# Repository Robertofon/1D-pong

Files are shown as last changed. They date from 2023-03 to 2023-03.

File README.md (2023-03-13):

# 1D-pong

This is an ESP32 (at least that) version of the all well known warareg 1-D Pong game
also known as `one_d_pong`.

This is a linear pong game where the bat is a home area of about 7 pixels. Depending on
how deep you let the ball run into your home area, the faster it is repelled. If you 
fail to press the button in time you loose a point since the ball enters your home.
This version supports a boost button which sacrefies one pixel of your home area in 
favor of boosting your ball faster.

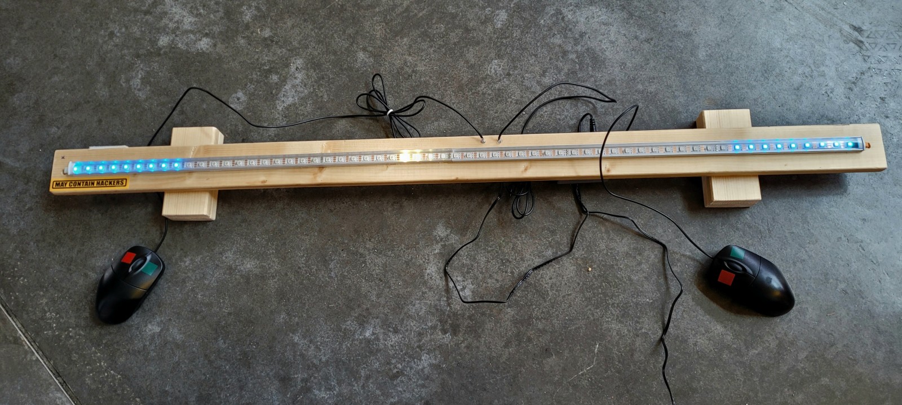
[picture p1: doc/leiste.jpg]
Full 1D-pong device


We discovered that using these Pins for I/O was a good choice

* GPIO21 = LED data (WS2812b)
* GPIO19 = Right start/hit button (Y)
* GPIO18 = Right power-up button  (Y)
* GPIO33 = Left start/hit button  (X)
* GPIO23 = Left power-up button   (X)
* SOUND GPIO32  = Buzzer output (PB1/OC1A)

Some pins do not allow to configure Pull up resistors or work only as output. Don't use them.

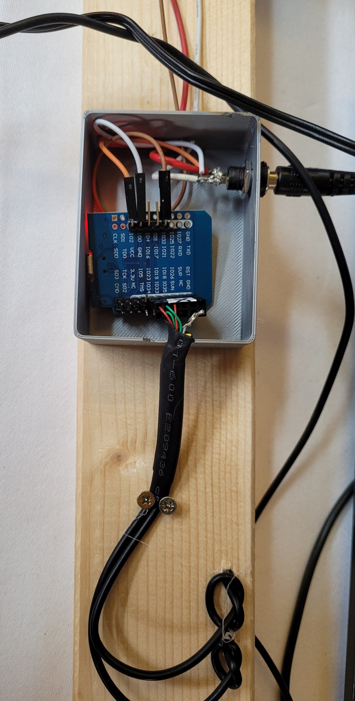
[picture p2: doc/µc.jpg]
The ESP32 of that shape with Pins connected


We used Mouse devices which where re-soldered to use the 4 USB wires as 'short to GND' to work as controllers. 
That is, each button got explicitly one of the Din, Dout, Vcc wires and shorts it to the GND wire of USB.
USB plugs where of course snipped off.
We also did re-solder some of the existing capacitors of the USB-logic board and put them in parallel to the
switch to suppress electric bouncing of the switch signal.

One way of wiring everything up (you can vary for geometry reasons) can be seen here.
We respected the types of PINs and their capability. i.e. all switch pins must support
pull up resistors (configurable property of ESP32) and work as digital input. 
The buzzer sound pin must be supported by the PWM generator. (Not yet used by the code)

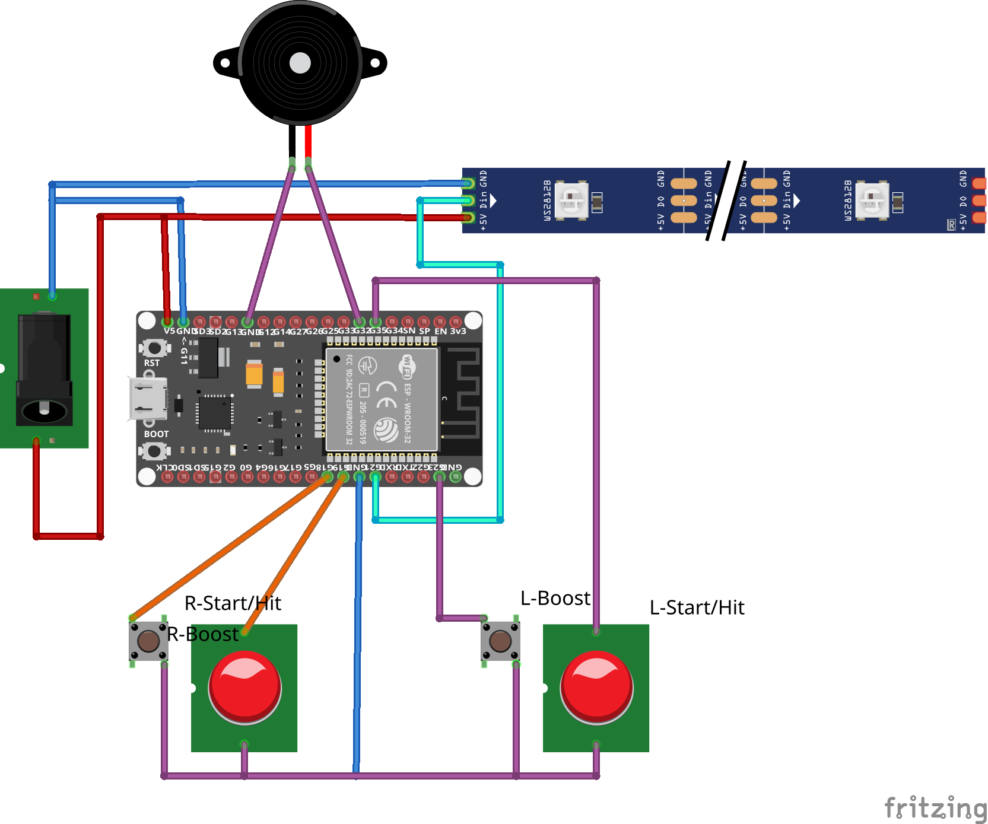
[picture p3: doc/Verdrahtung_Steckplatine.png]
Layout


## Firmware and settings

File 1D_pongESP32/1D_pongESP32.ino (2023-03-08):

/*
 * Arduino 1D Pong Game with (60) WS2812B LEDs
 *
 * Copyright (C) 2015  B.Stultiens
 *
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
 * Adapted by Robert Köpferl 2022 to be used on ESP32 -
 * no optimisation towards atmel
 *
 */

#include <Adafruit_NeoPixel.h>
#include "notes.h"
#include "pin-names.h"

#define NELEM(x) (sizeof(x) / sizeof((x)[0]))

#define PIN_WSDATA GPIO21 // LED data
#define PIN_BUT_RS GPIO19 // Right start/hit button (Y)
#define PIN_BUT_RP GPIO18 // Right power-up button  (Y)
#define PIN_BUT_LS GPIO33 // Left start/hit button  (X)
#define PIN_BUT_LP GPIO23 // Left power-up button   (X)
#define PIN_SOUND GPIO32  // Buzzer output (PB1/OC1A)

#define NPIXELS 60 // Number of pixels to handle

#define ZONE_SIZE 10		// Bounce-back zone size
#define SHOW_LO 12		// Score dots intensity background
#define SHOW_HI 48		// Score dots intensity foreground
#define WIN_POINTS 10	// Points needed to win
#define TONE_INTERVAL 5 // Not every ball move should give a sound

Adafruit_NeoPixel one_d = Adafruit_NeoPixel(NPIXELS, PIN_WSDATA, NEO_GRB | NEO_KHZ800);

// Events from buttons and timers
#define EV_BUT_LS_PRESS 0x01
#define EV_BUT_RS_PRESS 0x02
#define EV_BUT_LP_PRESS 0x04
#define EV_BUT_RP_PRESS 0x08
#define EV_TIMER 0x10
#define EV_TIMEOUT 0x20
#define EV_TONETIMER 0x40

#define TIME_DEBOUNCE 8
#define TIME_IDLE 40
#define TIME_START_TIMEOUT 20000 // Go idle if nothing happens
#define TIME_RESUME_TIMEOUT 7500 // Auto-fire after timeout
#define TIME_BALL_BLINK 150
#define TIME_SPEED_MIN 10
#define TIME_SPEED_INTERVAL 3
#define TIME_POINT_BLINK 233
#define TIME_WIN_BLINK 85
#define TIME_LOCKOUT 250 // Prevent fast button-press to max. 4 times/s

#define TIME_TONE_SERVE 50 // Sound durations
#define TIME_TONE_BOUNCE 50
#define TIME_TONE_MOVE 25
#define TIME_TONE_SCORE 50

enum
{
	ST_IDLE = 0,
	ST_START_L,
	ST_START_R,
	ST_MOVE_LR,
	ST_MOVE_RL,
	ST_ZONE_L,
	ST_ZONE_R,
	ST_POINT_L,
	ST_POINT_R,
	ST_RESUME_L,
	ST_RESUME_R,
	ST_WIN_L,
	ST_WIN_R,
};

static uint32_t oldtime; // Previous' loop millis() value
static uint8_t thestate; // Game state

static uint8_t bstate_ls; // Button states
static uint8_t bstate_rs;
static uint8_t bstate_lp;
static uint8_t bstate_rp;
static uint8_t debtmr_ls; // Button debounce timers
static uint8_t debtmr_rs;
static uint8_t debtmr_lp;
static uint8_t debtmr_rp;
static uint16_t timer;	   // General timer
static uint16_t timeout;   // Timeout timer (auto-start and goto idle)
static uint16_t tonetimer; // Tone duration timer
static uint16_t lockout_l; // Lockout timer to prevent pushing too often
static uint16_t lockout_r;
static uint8_t ballblinkstate;	// Blinking ball at edge on/off
static uint8_t pointblinkcount; // Blinking point when a side scores
static uint8_t ballpos;			// Current position of the ball
static uint16_t speed;			// Time between ball moves
static uint8_t speedup;			// Faster and faster replies counter
static uint8_t points_l;		// Score
static uint8_t points_r;
static uint8_t zone_l; // Hit back zone
static uint8_t zone_r;
static uint8_t boost_l; // Set if user boosted speed last round
static uint8_t boost_r;
static uint8_t boosted;	  // Set if any user boosted until the ball reaches opposite side
static uint8_t tonecount; // Interval counter for sound during move
static uint8_t tuneidx;	  // Index to the running tune

struct tnote
{
	uint8_t note;
	uint16_t duration;
};

/* Tone pitch table for 16MHz crystal */
static const uint16_t tone_pitch[NTONE_PITCH] PROGMEM = {
	61155,
	57722,
	54482,
	51424,
	48538,
	45814,
	43242,
	40815,
	38524,
	36362 /* == 220Hz */,
	34321,
	32395,
	30577,
	28860,
	27240,
	25711,
	24268,
	22906,
	21620,
	20407,
	19261,
	18180 /* == 440Hz */,
	17160,
	16197,
	15288,
	14429,
	13619,
	12855,
	12133,
	11452,
	10809,
	10203,
	9630,
	9089 /* == 880Hz */,
	8579,
	8098,
	7643,
	7214,
	6809,
	6427,
	6066,
	5725,
	5404,
	5101,
	4814,
	4544,
	4289,
	4048,
	3821,
	3606,
	3404,
	3213,
	3032,
	2862,
	2701,
	2550,
	2406,
	2271,
	2144,
	2023,
	1910,
};
static const tnote tune_win[] PROGMEM = {
	{NOTE_Gs6, DUR_1_16},
	{NOTE_A6, DUR_1_16},
	{NOTE_Gs6, DUR_1_16},
	{NOTE_E6, DUR_1_16},
	{NOTE_Gs6, DUR_1_16},
	{NOTE_A6, DUR_1_16},
	{NOTE_Gs6, DUR_1_16},
	{NOTE_E6, DUR_1_16},
	{0, DUR_1_8},
	{NOTE_D4, DUR_1_8},
	{NOTE_D4, DUR_1_8},
	{NOTE_B3, DUR_1_8},
	{NOTE_E4, DUR_1_8},
	{NOTE_D4, DUR_1_4},
	{NOTE_B3, DUR_1_4},
	{NOTE_D4, DUR_1_8},
	{NOTE_D4, DUR_1_8},
	{NOTE_B3, DUR_1_8},
	{NOTE_E4, DUR_1_8},
	{NOTE_D4, DUR_1_4},
	{NOTE_B3, DUR_1_4},
};

// #define sound_off()	do { TCCR1A = _BV(COM1A1); /* Set clear output */ } while(0)
void sound_off()
{
	// stop play
	//noTone(PIN_SOUND);
  ledcDetachPin(PIN_SOUND);
}

/*
 * Return the current state of a button.
 * Returns non-zero on button pressed.
 */
static inline uint8_t button_is_down(uint8_t pin)
{
	switch (pin)
	{
	case PIN_BUT_LS:
		return !debtmr_ls && !bstate_ls;
	case PIN_BUT_RS:
		return !debtmr_rs && !bstate_rs;
	case PIN_BUT_LP:
		return !debtmr_lp && !bstate_lp;
	case PIN_BUT_RP:
		return !debtmr_rp && !bstate_rp;
	}
	return 0;
}

/*
 * Debounce a button and return an event at the rising edge of the detection.
 * The rising edge ensures that there is no delay from pressing the button and
 * the event propagating. It is a prerequisite that the input line is not
 * glitchy.
 * A release event may be generated if the routine is slightly modified.
 */
static inline uint8_t do_debounce(uint8_t tdiff, uint8_t *bstate, uint8_t *debtmr, uint8_t pin, uint8_t ev)
{
	if (0 == *debtmr)
	{
		uint8_t state = digitalRead(pin);
		if (state != *bstate)
		{
			*debtmr = TIME_DEBOUNCE;
			if (!(*bstate = state))
				return ev; // Event on High-to-Low transition of input
						   // else
						   //  return release_event_value
		}
	}
	else
	{
		if (*debtmr >= tdiff)
			*debtmr -= tdiff;
		else
			*debtmr = 0;
	}
	return 0;
}

/*
 * Timer countdown and return an event on timer reaching zero.
 */
static inline uint8_t do_timer(uint8_t tdiff, uint16_t *tmr, uint8_t ev)
{
	if (0 != *tmr)
	{
		if (*tmr >= tdiff)
			*tmr -= tdiff; // Timer countdown
		else
			*tmr = 0;
		// Set event when done counting
		if (0 == *tmr)
			return ev;
	}
	return 0;
}

/*
 * Set the speaker to generate a tone
 */
static inline void set_tone(uint16_t note, uint16_t duration)
{
	tonetimer = duration;
	if (note && note <= NTONE_PITCH)
	{
		// to calculate the note duration, take one second divided by the note type.
		//e.g. quarter note = 1000 / 4, eighth note = 1000/8, etc.
		//int noteDuration = 1000 / noteDurations[thisNote];
//		uint16_t pitch = pgm_read_word(&tone_pitch[note-1]);
//    const int sndChannel = 0;
//    ledcSetup(sndChannel, pitch, 8);
//    ledcAttachPin(PIN_SOUND, sndChannel);
//    ledcWrite(sndChannel, 255);
		//tone(PIN_SOUND, pitch, duration)
		// TCCR1A = _BV(COM1A0);	/* Set toggle output */
		// TCNT1 = 0;
	}
	else
		sound_off();
}

/*
 * Play the next note of the tune
 */
static inline void tune_next()
{
	if (tuneidx < NELEM(tune_win))
	{
		uint16_t n = pgm_read_byte(&tune_win[tuneidx].note);
		uint16_t d = pgm_read_word(&tune_win[tuneidx].duration);
		set_tone(n, d);
		tuneidx++;
	}
	else
		set_tone(0, 0);
}

/*
 * Draw the left and right zones where the ball may be hit back.
 */
static void draw_sides()
{
	for (uint8_t i = 0; i < zone_l - 1; i++)
	{
		one_d.setPixelColor(i, 0, 64, 64);
	}
	one_d.setPixelColor(0, 0, 64, 64);
	for (uint8_t i = 0; i < zone_r - 1; i++)
	{
		one_d.setPixelColor(NPIXELS - 1 - i, 0, 64, 64);
	}
	one_d.setPixelColor(NPIXELS - 1, 0, 64, 64);
}

/*
 * Draw the ball with a tail of five pixels in diminishing intensity.
 */
static void draw_ball(int8_t dir, uint8_t pos)
{
	uint8_t c = 255;
	for (uint8_t i = 0; i < 5 && pos >= 0 && pos < NPIXELS; i++)
	{
		one_d.setPixelColor(pos, c, c, 0);
		c /= 3;
		pos -= dir;
	}
}

/*
 * Draw the playing field consisting of the zones and the points scored so far.
 */
static void draw_course(uint8_t v)
{
	one_d.clear();
	draw_sides();
	if (v)
	{
		for (uint8_t i = 0; i < points_l; i++)
		{
			one_d.setPixelColor(NPIXELS / 2 - 1 - (2 * i + 0), v, 0, 0);
			one_d.setPixelColor(NPIXELS / 2 - 1 - (2 * i + 1), v, 0, 0);
		}
		for (uint8_t i = 0; i < points_r; i++)
		{
			one_d.setPixelColor(NPIXELS / 2 + (2 * i + 0), 0, v, 0);
			one_d.setPixelColor(NPIXELS / 2 + (2 * i + 1), 0, v, 0);
		}
	}
}

/*
 * Animate the game idle situation with following content:
 * - A rainbow pattern
 * - Ball bouncing left-right-left-right
 * - Score animation
 */
static uint16_t ai_h;
static uint8_t ai_state;
static uint8_t ai_pos;

static void animate_idle_init(void)
{
	ai_h = 0;
	ai_state = 0;
}

#define H_STEPS 1542

static void animate_idle(void)
{
	switch (ai_state)
	{
	case 0:
	case 1:
	case 2:
	case 3:
		/* Rainbow pattern */
		for (uint8_t i = 0; i < NPIXELS; i++)
		{
			uint16_t h = ai_h + (i << 4);
			if (h >= H_STEPS)
				h -= H_STEPS;
			//*one_d.setPixelColorHsv(i, h, 255, 128);
		}
		ai_h += H_STEPS / 60;
		if (ai_h >= H_STEPS)
		{
			ai_h -= H_STEPS;
			ai_pos = 0;
			ai_state++;
		}
		break;
	case 4:
	case 6:
		/* Ball left-to-right */
		draw_course(0);
		draw_ball(1, ai_pos++);
		if (ai_pos >= NPIXELS)
		{
			ai_state++;
		}
		break;
	case 5:
	case 7:
		/* Ball right-to-left */
		draw_course(0);
		draw_ball(-1, --ai_pos);
		if (!ai_pos)
		{
			ai_state++;
		}
		break;
	case 8:
	case 10:
		/* Score blinkenlights */
		draw_course(0);
		for (uint8_t i = 0; i < ai_pos; i++)
		{
			one_d.setPixelColor(NPIXELS / 2 - 1 - i, 255, 0, 0);
			one_d.setPixelColor(NPIXELS / 2 + i, 0, 255, 0);
		}
		if (++ai_pos >= NPIXELS / 2)
		{
			ai_state++;
			ai_pos = 0;
		}
		break;

	case 9:
	case 11:
		draw_course(0);
		for (uint8_t i = 0; i < NPIXELS / 2 - ai_pos; i++)
		{
			one_d.setPixelColor(NPIXELS / 2 - 1 - i, 255, 0, 0);
			one_d.setPixelColor(NPIXELS / 2 + i, 0, 255, 0);
		}
		if (++ai_pos >= NPIXELS / 2)
		{
			ai_state++;
			ai_pos = 0;
		}
		break;

	default:
		ai_state = 0;
		break;
	}
	one_d.show();
}

/*
 * Animate a winner. Flash the winning side's points.
 */
static uint8_t aw_state;
static void animate_win_init()
{
	aw_state = 0;
}

static uint8_t animate_win(uint8_t side)
{
	uint32_t clr;
	uint8_t pos;

	if (side)
	{
		clr = Adafruit_NeoPixel::Color(0, 255, 0);
		pos = NPIXELS / 2;
	}
	else
	{
		clr = Adafruit_NeoPixel::Color(255, 0, 0);
		pos = 0;
	}

	one_d.clear();
	if (aw_state < 20)
	{
		if (aw_state & 0x01)
		{
			for (uint8_t i = 0; i < NPIXELS / 2; i++)
			{
				one_d.setPixelColor(pos + i, clr);
			}
		}
	}
	else if (aw_state < 50)
	{
		for (uint8_t i = 0; i < aw_state - 20; i++)
		{
			one_d.setPixelColor(pos + i, clr);
		}
	}
	else if (aw_state < 80)
	{
		for (uint8_t i = aw_state - 50; i < NPIXELS / 2; i++)
		{
			one_d.setPixelColor(pos + i, clr);
		}
	}
	else if (aw_state < 110)
	{
		for (uint8_t i = 0; i < aw_state - 80; i++)
		{
			one_d.setPixelColor(NPIXELS / 2 - 1 - i + pos, clr);
		}
	}
	else if (aw_state < 140)
	{
		for (uint8_t i = aw_state - 110; i < NPIXELS / 2; i++)
		{
			one_d.setPixelColor(NPIXELS / 2 - 1 - i + pos, clr);
		}
	}
	one_d.show();
	return ++aw_state < 140;
}

/*
 * Active game states suppress fast button pushes
 */
static uint8_t is_game_state(uint8_t s)
{
	switch (s)
	{
	case ST_MOVE_LR: // If you press too soon
	case ST_MOVE_RL:
	case ST_ZONE_R: // In the zone
	case ST_ZONE_L:
	case ST_POINT_L: // Just got a point, delay resume
	case ST_POINT_R:
	case ST_WIN_R: // Delay to activate the win sequence
	case ST_WIN_L:
		return 1;
	default:
		return 0;
	}
}

/*
 * Set the timer to the speed of the ball and the current boost-state
 */
static inline void speed_to_timer()
{
	if (boosted)
		timer = speed * 3 / 4;
	else
		timer = speed;
	if (timer < 2)
		timer = 2;
}

/*
 * State transition routine. Setup prerequisites for the new state to function
 * properly.
 * - Handle a state's exit actions
 * - Handle a state's entry actions
 */
static void set_state(uint8_t newstate)
{
	/* State exit actions */
	switch (thestate)
	{
	case ST_IDLE:
	case ST_WIN_L:
	case ST_WIN_R:
		points_l = points_r = 0;
		boost_l = boost_r = 0;
		zone_l = zone_r = ZONE_SIZE;
		speedup = 0;
		boosted = 0;
		break;

	case ST_START_L:
	case ST_POINT_L:
	case ST_RESUME_L:
		ballpos = 0;
		/* Serve speed not too fast */
		speed = TIME_SPEED_MIN + 5 * TIME_SPEED_INTERVAL;
		speedup = 0;
		break;

	case ST_START_R:
	case ST_POINT_R:
	case ST_RESUME_R:
		ballpos = NPIXELS - 1;
		/* Serve speed not too fast */
		speed = TIME_SPEED_MIN + 5 * TIME_SPEED_INTERVAL;
		speedup = 0;
		break;

	case ST_ZONE_L:
		/* Calculate the speed for the return */
		speed = TIME_SPEED_MIN + TIME_SPEED_INTERVAL * ballpos;
		if (++speedup / 2 >= speed)
			speed = 2;
		else
			speed -= speedup / 2;
		boosted = 0;
		break;

	case ST_ZONE_R:
		/* Calculate the speed for the return */
		speed = TIME_SPEED_MIN + TIME_SPEED_INTERVAL * (NPIXELS - 1 - ballpos);
		if (++speedup / 2 >= speed)
			speed = 2;
		else
			speed -= speedup / 2;
		boosted = 0;
		break;
	}

	thestate = newstate;
	/* State entry actions */
	switch (thestate)
	{
	case ST_IDLE:
		boost_l = boost_r = 0;
		zone_l = zone_r = ZONE_SIZE;
		animate_idle_init();
		timer = TIME_IDLE;
		break;

	case ST_START_L:
	case ST_START_R:
		draw_course(SHOW_HI);
		one_d.show();
		timer = TIME_BALL_BLINK;
		timeout = TIME_START_TIMEOUT;
		ballblinkstate = 0;
		ballpos = thestate == ST_START_L ? 0 : NPIXELS - 1;
		break;

	case ST_MOVE_LR:
	case ST_MOVE_RL:
		speed_to_timer();
		tonecount = TONE_INTERVAL;
		break;

	case ST_POINT_L:
	case ST_POINT_R:
		pointblinkcount = 7;
		/* Recover the zone next round */
		if (!boost_l && zone_l < ZONE_SIZE)
			zone_l++;
		if (!boost_r && zone_r < ZONE_SIZE)
			zone_r++;
		timer = TIME_POINT_BLINK;
		if (boost_l)
			boost_l--;
		if (boost_r)
			boost_r--;
		// Ensure we get to the score display before continuing
		lockout_l = lockout_r = TIME_LOCKOUT;
		break;

	case ST_RESUME_L:
	case ST_RESUME_R:
		draw_course(SHOW_HI);
		one_d.show();
		timer = TIME_BALL_BLINK;
		timeout = TIME_RESUME_TIMEOUT;
		ballblinkstate = 0;
		break;

	case ST_WIN_L:
	case ST_WIN_R:
		// Ensure we get to the winner display before continuing
		lockout_l = lockout_r = 2 * TIME_LOCKOUT;
		animate_win_init();
		timer = TIME_WIN_BLINK;
		tuneidx = 0;
		tune_next();
		break;
	}
}

/*
 * Arduino setup
 */
void setup()
{
	// PORTB = PORTC = PORTD = 0xff;	// Enable all pull-ups so we don't have undef inputs hanging

	// We use the internal PullUp-Resistors in the ESP - thus saving wires and resistors
	// outside. Then buttons must only connect the GPIO pin with GND - easy!
	pinMode(PIN_BUT_LS, INPUT_PULLUP);
	pinMode(PIN_BUT_RS, INPUT_PULLUP);
	pinMode(PIN_BUT_LP, INPUT_PULLUP);
	pinMode(PIN_BUT_RP, INPUT_PULLUP);
	// Not need digitalWrite(PIN_SOUND, 0);
	pinMode(PIN_SOUND, OUTPUT);

	one_d.begin(); // Setup IO
				   // Test rob
	one_d.setBrightness(60);
	one_d.setPixelColor(6, one_d.Color(200, 200, 0));
	one_d.show(); // All leds off

	thestate = ST_IDLE;
	set_state(ST_IDLE); // To run both exit and entry actions

	/*
	 * Setup sound hardware with Timer1 manually. The disabled interrupts
	 * in the pixel-update causes interference in the timing resulting in
	 * clicks in the sound output.
	 */
	/* geht nicht bei ESP32 - müsen was eigenes finden
	  TCCR1A = 0;
	  TCCR1B = _BV(WGM12) | _BV(CS10);
	  OCR1A = NOTE_C4;	// Just a value
	  TCNT1 = 0;
	*/
}

/*
 * Main program, called constantly and forever.
 *
 * - Handle timing and generate events
 * - Run the game's state machine
 */
#define chk_ev(ev) (events & (ev))
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

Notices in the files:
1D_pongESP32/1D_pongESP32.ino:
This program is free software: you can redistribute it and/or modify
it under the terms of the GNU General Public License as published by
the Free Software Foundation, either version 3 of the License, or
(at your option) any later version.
